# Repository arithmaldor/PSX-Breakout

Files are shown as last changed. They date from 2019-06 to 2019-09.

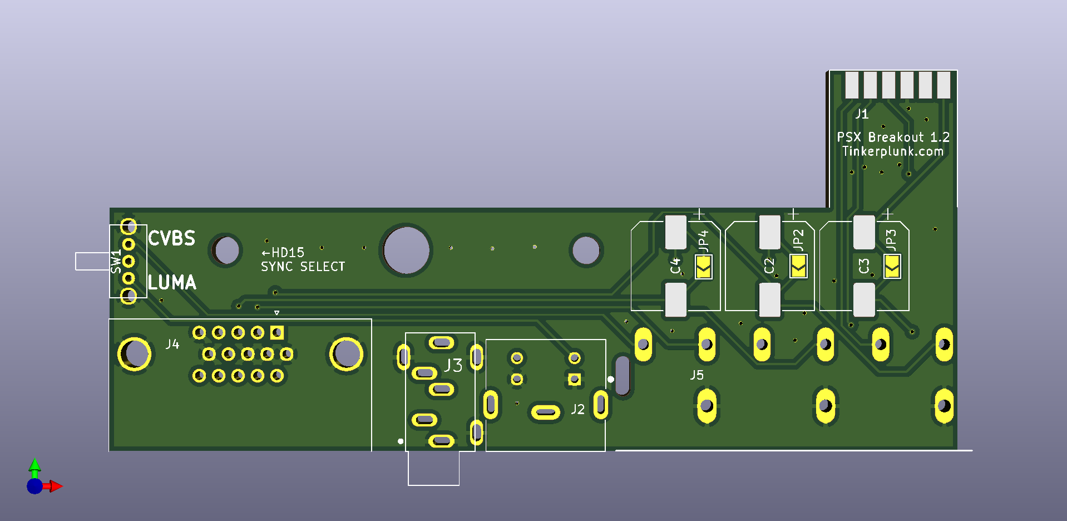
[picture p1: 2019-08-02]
Renders/Top.png

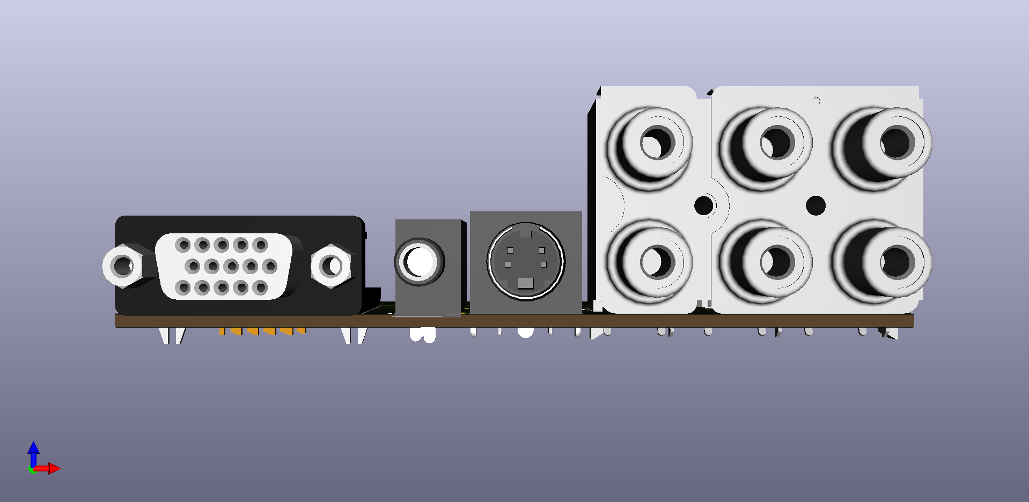
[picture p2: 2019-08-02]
Renders/Front 3D.png

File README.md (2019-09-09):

# Copyright and Disclaimer
Copyright: Jacob Proctor

This documentation describes Open Hardware and is licensed under the
CERN OHL v. 1.2.

You may redistribute and modify this documentation under the terms of the
CERN OHL v.1.2. (http://ohwr.org/cernohl). This documentation is distributed
WITHOUT ANY EXPRESS OR IMPLIED WARRANTY, INCLUDING OF
MERCHANTABILITY, SATISFACTORY QUALITY AND FITNESS FOR A
PARTICULAR PURPOSE. Please see the CERN OHL v.1.2 for applicable
conditions

# PSX Breakout
Breaks out all of the signals from the PSX AV out so you can easily access them. 

# Operation
Plug in and go.

## HD15 SYNC Selector 
Located on the back left of the board, this switch determines which signal goes to the HD15 port - CVBS or LUMA.

# Parts
Refer to BOM.csv for all components. For the support leg, use any appropriately long brass/metal m3 standoff/pillar and screw a rubber foot to the bottom. Solder a 5mm spring clamp to the bottom of the board to adjust the height.
For the phat PS3, standoffs may need to be screwed into each other (stacked) to reach the needed height.

# Case
The incredible [Magic Trashman](https://twitter.com/MagicTrashman) was kind enough to design 3D printable cases for both my Nintendo and PSX breakouts. They are under the same license as the PCB and are free to use, but if you order through thingiverse you can leave him a nice tip. Current designs fit the height of the original PS1 and the original SNES, but can be easily adjusted for height if you have some basic 3D design skills. They are held together with 2x 14mm M3 machine screws.
Pictures: https://t.co/ojJ8epfZXH?amp=1
Thingiverse: https://t.co/7dF171BqaF?amp=1
Bonus: If you plug the Nintendo/Sony connector into the console and screw the PCB into the bottom of the case, it makes it a lot easier to solder the connector to the board as it is held in place.

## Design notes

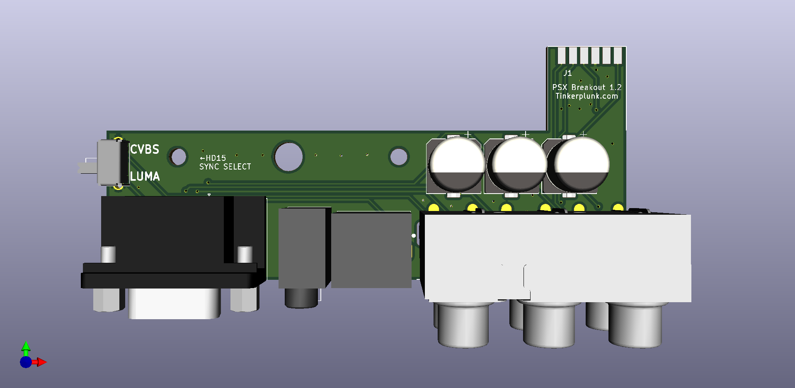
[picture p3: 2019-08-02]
Renders/Top 3D.png

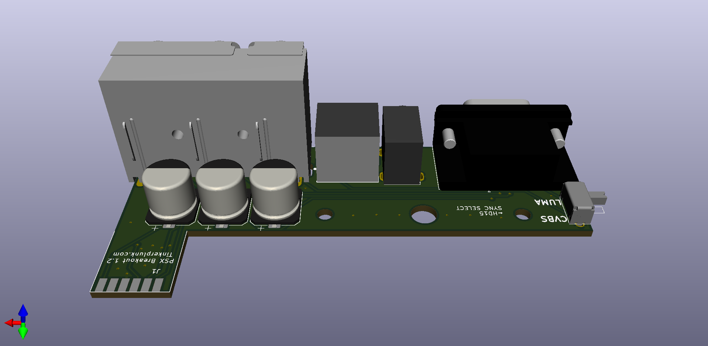
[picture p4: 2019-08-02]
Renders/Back 3D.png

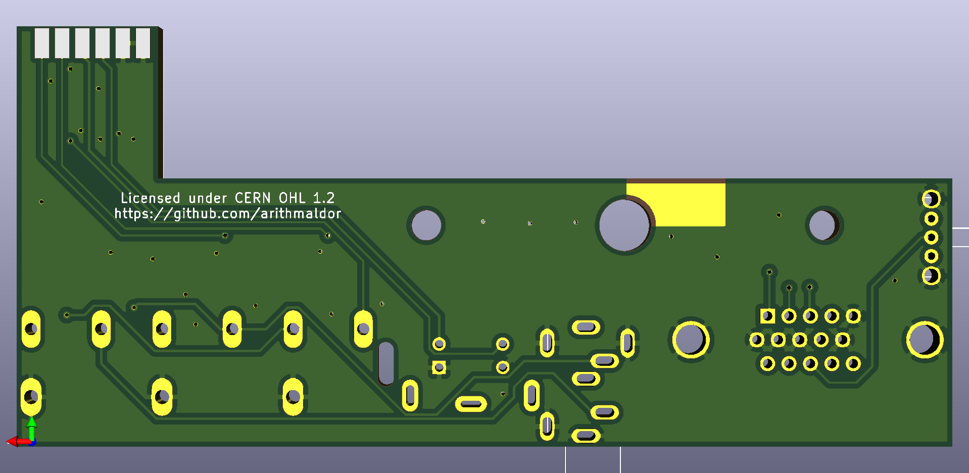
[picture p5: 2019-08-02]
Renders/Bottom.png

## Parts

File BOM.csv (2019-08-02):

Reference | Value | Footprint | MPN | Datasheet | Link | Alt Link | Alt Link 2 | Qty
C1-C3 | 220uF (PS1) | 10x10 | UUD1H221MNL1GS | http://nichicon-us.com/english/products/pdfs/e-uud.pdf | https://www.digikey.com/product-detail/en/nichicon/UUD1H221MNL1GS/493-2308-1-ND/590283 | https://www.arrow.com/en/products/uud1h221mnl1gs/nichicon | https://lcsc.com/product-detail/Aluminum-Electrolytic-Capacitors-SMD_Nichicon_UUD1H221MNL1GS_220UF-50V_C125976.html | 3
C1-C3 | DNI (PS2+PS3 only) | N/A | N/A | N/A | N/A | N/A | N/A | 0
C1-C3 | 1000uF (all PSX models) | 10x10 | UUD1A102MNL1GS | http://nichicon-us.com/english/products/pdfs/e-uud.pdf | https://www.digikey.com/product-detail/en/nichicon/UUD1A102MNL1GS/493-2254-1-ND/590229 | https://www.arrow.com/en/products/uud1a102mnl1gs/nichicon | https://lcsc.com/product-detail/Others_Lelon-VE-102M0J1010-TRO_C249473.html | 3
J1 | PSX AV Connector | PSX_BREAKOUT:PSX_AV |  |  | https://console5.com/store/sony-playstation-1-2-ps1-ps2-av-multi-out-plug-for-custom-rgb-cables-repair.html |  |  | 1
J2 | S-Video | Mini Din 4 | MD-40 S, SG, SM or SGK | http://service.powerdynamics.com/ec/Catalog17/Section%2011.pdf | https://www.digikey.com/product-detail/en/cui-inc/MD-40SM/CP-2240-ND/96935 | https://www.arrow.com/en/products/md-40sm/cui-inc |  | 1
J3 | Headphone Jack | 3 pin | SJ1-3533NG | https://www.cui.com/product/resource/digikeypdf/sj1-353xng.pdf | https://www.digikey.com/product-detail/en/cui-inc/SJ1-3533NG/CP1-3533NG-ND/738701 | https://www.arrow.com/en/products/sj1-3533ng/cui-inc | https://lcsc.com/product-detail/Audio-Video-Connectors_Boom-Precision-Elec-3-5mmAudio-sockets-PJ325_C26230.html | 1
J4 | DB15 Female High Density | DB15 HD Female | ICD15S13E6GV00LF | https://www.amphenol-icc.com/media/wysiwyg/files/drawing/c-cd-0012.pdf | https://www.digikey.com/product-detail/en/amphenol-icc-fci/ICD15S13E6GV00LF/609-2802-ND/1090326 | https://www.arrow.com/en/products/icd15s13e6gv00lf/amphenol-fci | https://lcsc.com/product-detail/D-Sub-Connectors_VGA-002_C138387.html | 1
J5 | 3x2_RCA | Stacked RCA 2 high 3 long. LR,TB: GBRYWR | RCA-628N1-14 |  | https://ebay.us/PmOF6q |  |  | 1
SW1 | SW_SPDT | PSX_BREAKOUT:C&K_SPDT | OS102011MA1QN1 | https://www.ckswitches.com/media/1428/os.pdf | https://www.digikey.com/products/en?keywords=OS102011MA1QN1%20 | https://www.arrow.com/en/products/os102011ma1qn1/ck | https://lcsc.com/product-detail/Toggle-Switches_Korean-Hroparts-Elec-SK-12D02-VG5_C136722.html | 1

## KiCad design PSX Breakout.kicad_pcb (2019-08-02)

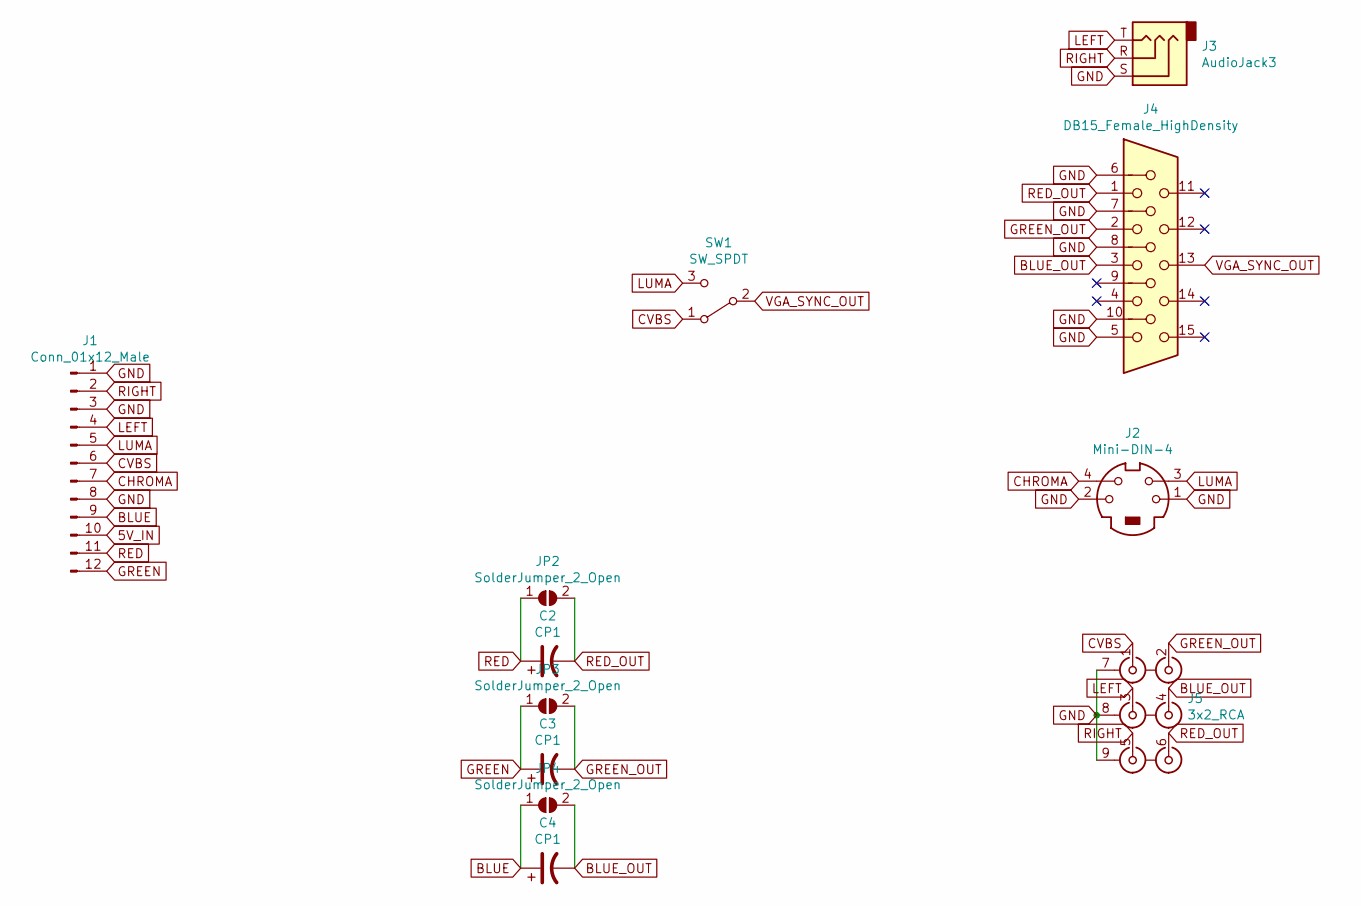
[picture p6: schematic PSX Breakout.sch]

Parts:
C2, C3, C4: CP1; CP_Elec_10x10
J1: Conn_01x12_Male; PSX_AV
J2: Mini-DIN-4; CUI_MD-40SG
J3: AudioJack3; CUI_SJ1-3533NG
J4: DB15_Female_HighDensity; VGA
J5: 3x2_RCA
JP2, JP3, JP4: SolderJumper_2_Open; SolderJumper-2_P1.3mm_Open_TrianglePad1.0x1.5mm
SW1: SW_SPDT; C&K_SPDT

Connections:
5V_IN: J1.10
BLUE: C4.1, J1.9, JP4.1 (A)
BLUE_OUT: C4.2, J4.3, J5.4 (INGRN), JP4.2 (B)
CHROMA: J1.7, J2.4
CVBS: J1.6, J5.1 (INSYN), SW1.1 (A)
GND: J1.1, J1.3, J1.8, J2.1, J2.2, J3.S, J4.0, J4.5, J4.6, J4.7, J4.8, J4.10, J5.7 (GND), J5.8 (GND), J5.9 (GND), SW1.S
GREEN: C3.1, J1.12, JP3.1 (A)
GREEN_OUT: C3.2, J4.2, J5.2 (INRED), JP3.2 (B)
LEFT: J1.4, J3.T, J5.3 (INLAU)
LUMA: J1.5, J2.3, SW1.3 (C)
RED: C2.1, J1.11, JP2.1 (A)
RED_OUT: C2.2, J4.1, J5.6 (INBLU), JP2.2 (B)
RIGHT: J1.2, J3.R, J5.5 (INRAU)
VGA_SYNC_OUT: J4.13, SW1.2 (B)

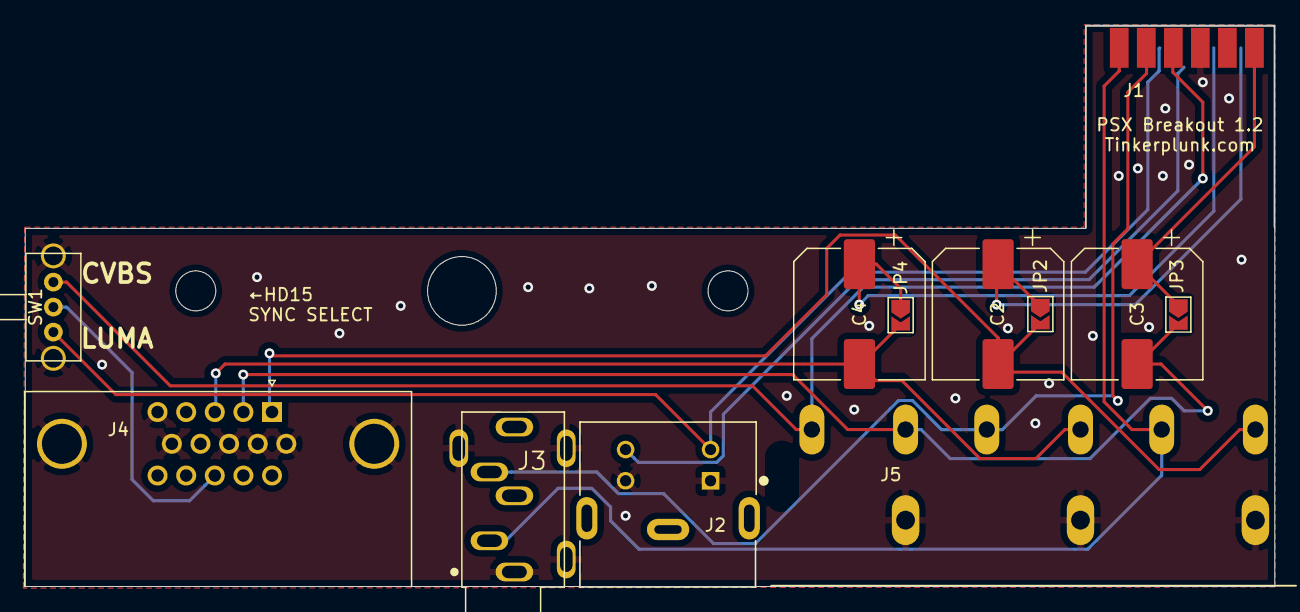
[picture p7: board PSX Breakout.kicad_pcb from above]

Board: 2 copper layers, 100.0 x 44.9 mm, 12 parts (0 on the bottom side), 13 nets.

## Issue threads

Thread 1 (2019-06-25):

Fix Headphone Jack Footprint

arithmaldor, 2019-06-25:
All pads have too small drill holes

Closed 2019-06-25.

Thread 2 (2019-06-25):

Fix S-Video Footprint

arithmaldor, 2019-06-25:
Ground/shield pads have too small drill holes.

Closed 2019-06-25.

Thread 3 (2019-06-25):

BOM is missing

arithmaldor, 2019-06-25:
gitignore for kicad includes .csv files by default for some reason

Closed 2019-06-25.

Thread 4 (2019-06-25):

Improve PSX Connector Footprint

arithmaldor, 2019-06-25:
The spacing on the PSX connector footprint works but it could be better. Originally designed by measuring the distance between 2 pins and using that, so the error propagated and it was off by the time I got to the end of the row. Measure the total distance and divide next time.

arithmaldor, 2019-08-09:
Honestly it's fine, good enough.

Closed 2019-08-09.

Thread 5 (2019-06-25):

Update Hardware BOM

arithmaldor, 2019-06-25:
Update Hardware BOM after finding a better solution for the feet.

arithmaldor, 2019-07-31:
found better solution, only generic m3 brass standoffs needed. Exact height is not important, just needs to be taller than you need. Multiple standoffs can be stacked. Rubber foot and screw on bottom foot, metal 5mm hose clamp soldered to bottom of board.

Closed 2019-07-31.

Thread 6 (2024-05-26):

More Specific BOM?

GK6475, 2024-05-26:
I'm looking to build one or more of these for myself and the BOM does not seem to be specific on what exact components are needed to properly build this board. Can you please update the BOM?

GK6475, 2024-05-26:
Never mind, found it in the 1.2 release.

Closed 2024-05-26.

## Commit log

2019-06-09 Updated Case Gerbers
    [Case top+bottom.kicad_pcb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]
2019-06-09 Update Case top+bottom.kicad_pcb
    [Case top+bottom.kicad_pcb]
2019-06-09 Case edit, renders
    moved the case back a bit behind the RCA jacks to give space, added renders that include the case.
    [Case top_bottom-B_Cu.gbl, Case top_bottom-B_Mask.gbs, Case top_bottom-B_SilkS.gbo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]
2019-06-09 Update PSX Breakout.kicad_pcb
    [PSX Breakout.kicad_pcb]
2019-06-11 Fixing Merging Error
    Updated Case, moved connector, generated gerbers
    [Case top_bottom-B_Mask.gbs, Case top_bottom-F_Cu.gtl, Case top_bottom-F_Mask.gts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]
2019-06-13 Changed headphone jack footprint
    Added pins to the headphone jack footprint so it is compatible with all SJ1-353x-n, ng, and ns series jacks.
    [PSX Breakout-B_Cu.gbl, PSX Breakout-B_Mask.gbs, PSX Breakout-B_SilkS.gbo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]
2019-06-13 Completed BOM
    [BOM.ods, PSX Breakout.kicad_pcb]
2019-06-16 Big Changes
    Moved the csync selector switch to the right in order to move the hd15 connector back to the right position. Fixed hd15 footprint, moved screw holes and updated case with new screw holes and input labels. Updated 3d model for HD15 connector.
    [PSX Breakout-B_Cu.gbl, PSX Breakout-B_Mask.gbs, PSX Breakout-B_SilkS.gbo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]
2019-06-17 Updated BOM
2019-06-17 Fixed Gerbers, added footprints
    Updated gerbers, and added all footprints used on this board to the PSX_BREAKOUT.Pretty folder.
    [PSX Breakout-B_Cu.gbl, PSX Breakout-B_Mask.gbs, PSX Breakout-B_SilkS.gbo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]
2019-06-18 Added Hardware BOM
    Added hardware BOM and diagram, updated readme.
2019-06-25 Fixed s-video and headphone footprint, added support hole
    [BOM.csv, Hardware_BOM.csv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]
2019-07-06 Updated to 1.2
    Removed sync stripper, shrunk board, added switch to select sync source of HD15 port only.
    [PSX Breakout-B_Cu.gbl, PSX Breakout-B_Mask.gbs, PSX Breakout-B_SilkS.gbo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]
2019-07-31 Changed s-video footprint
    [PSX Breakout-B_Cu.gbl, PSX Breakout-B_Mask.gbs, PSX Breakout-B_SilkS.gbo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]
2019-08-02 Finishing Touches
    [BOM.csv, Hardware_BOM.csv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]
2019-09-09 Add links for case files

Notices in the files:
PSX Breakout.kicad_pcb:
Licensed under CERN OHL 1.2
